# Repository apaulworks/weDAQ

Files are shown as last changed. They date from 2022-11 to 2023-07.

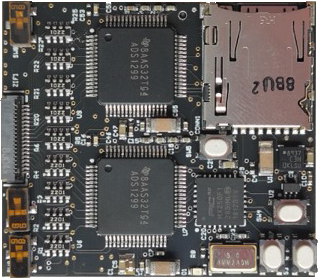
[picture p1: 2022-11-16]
images/Top board view.png

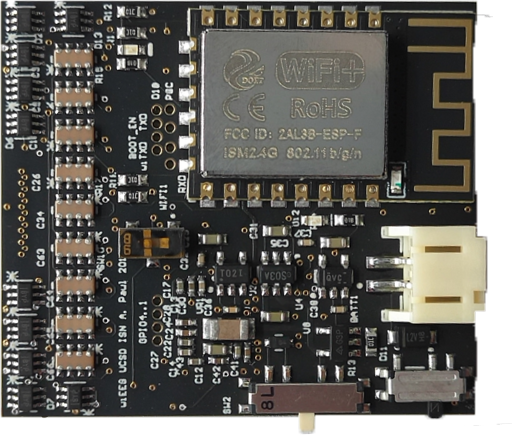
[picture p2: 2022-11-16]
images/Bottom board view.png

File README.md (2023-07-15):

# Wireless Electrophysiology Data Acquisition System (weDAQ)
 Hardware design files and PCB fabrication outputs for the Wireless Electrophysiology Data Acquisition (weDAQ) system. For more information, see: <br />
 the IEEE ISCAS 2022 Proceedings paper here: https://ieeexplore.ieee.org/document/9937994 <br />
 and the IEEE Transactions on Biomedical Circuits and Systems paper here: https://ieeexplore.ieee.org/abstract/document/10115033

## System Overview
<p align="left">
  banner
</p>
<p align="left">
  Wireless electrophysiology data acquisition (weDAQ) in the setting of a body-sensor network where multiple devices are deployed onto a subject or cohort of subjects.
</p>

## Assembled System 
### Top View
<p align="left">
  banner
  
</p>

### Bottom View
<p align="left">
  banner
</p>

<object data="/images/weDAQ_system_overview.pdf/" type="application/pdf" width="700px" height="700px">
    <embed src="/images/weDAQ_system_overview.pdf/">
        <p>This browser does not support PDFs. Please download the PDF to view it: <a href="/images/weDAQ_system_overview.pdf/">Download PDF</a>.</p>
    </embed>
</object>

Firmware and software repo associated with the weDAQ hardware are made available as well. <br />
Python control script: https://github.com/msl052/WeDAQ_Multi

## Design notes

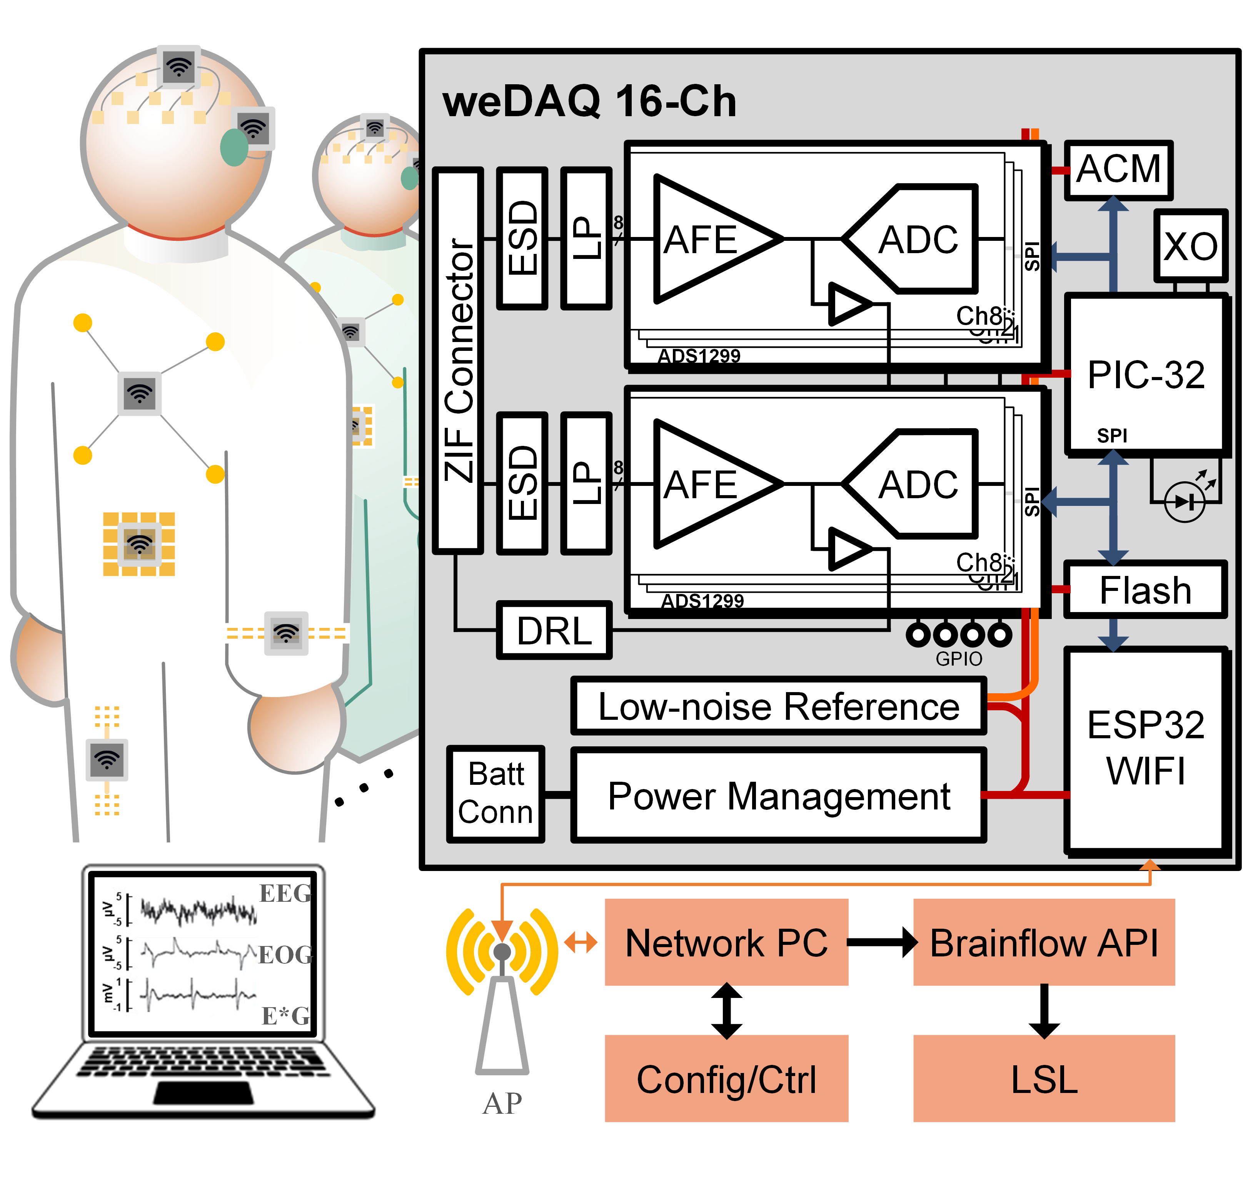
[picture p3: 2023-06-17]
images/Fig1_overview_diagram_2subjects.png

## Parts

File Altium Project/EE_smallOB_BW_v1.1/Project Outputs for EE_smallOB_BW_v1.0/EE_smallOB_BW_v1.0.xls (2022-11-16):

Line # | Name | Description | Designator | Quantity | Manufacturer 1 | Manufacturer Part Number 1 | Manufacturer Lifecycle 1 | Supplier 1 | Supplier Part Number 1 | Supplier Unit Price 1 | Supplier Subtotal 1
1 | S2B-PH-SM4-TB(LF)(SN) |  | BATT1 | 1 | JST | S2B-PH-SM4-TB(LF)(SN) | Unknown | Digi-Key | 455-1749-1-ND | 0.58 | 0.58
2 | GRM188C80G106KE47D | CAP CER 10UF 4V X6S 0603 | C1, C8, C25, C29, C31, C33, C37, C43, C46 | 9 | Murata | GRM188C80G106KE47D | Volume Production | Digi-Key | 490-10469-1-ND | 0.118 | 1.18
3 | GRM31CR60J107ME39K | MURATA - GRM31CR60J107ME39K - COND, 100µF, 6.3V, 20%, X5R, 1206 | C2, C4, C44, C45 | 4 | Murata | GRM31CR60J107ME39K | Obsolete | Digi-Key | 490-7217-1-ND | 0.98 | 3.92
4 | CA064C102K5RACTU | CAP ARRAY 1000PF 50V X7R 0612 | C3, C9, C11, C26, C34, C63, C64, C65, C66 | 9 | KEMET | CA064C102K5RACTU | Volume Production | Digi-Key | 399-9415-1-ND | 0.428 | 4.28
5 | CC0402KRX7R7BB104 | CAP CER 0.1UF 16V X7R 0402 | C5, C10, C12, C13, C15, C24, C28, C41, C47, C51 | 10 | Yageo | CC0402KRX7R7BB104 | Volume Production | Digi-Key | 311-1338-1-ND | 0.031 | 0.31
6 | GRM155R70J105KA12J | CAP CER 1UF 6.3V X7R 0402 | C6, C7, C14, C17, C18, C19, C21, C22, C27, C42, C54, C55, C58, C59, C60 | 15 | Murata | GRM155R70J105KA12J | New Product | Digi-Key | 490-13339-1-ND | 0.079 | 1.19
7 | CC0402KRX7R7BB102 | CAP CER 1000PF 16V X7R 0402 | C16, C53 | 2 | Yageo | CC0402KRX7R7BB102 | Volume Production | Digi-Key | 311-1352-1-ND | 0.019 | 0.19
8 | CC0402JRNPO9BN180 | CAP CER 18PF 50V C0G/NPO 0402 | C20, C23 | 2 | Yageo | CC0402JRNPO9BN180 | Volume Production | Digi-Key | 311-1415-1-ND | 0.1 | 0.2
9 | CC0402KRX7R7BB103 | CAP CER 10000PF 16V X7R 0402 | C30 | 1 | Yageo | CC0402KRX7R7BB103 | Volume Production | Digi-Key | 311-1042-1-ND | 0.1 | 0.1
10 | GRM155C80J225ME95D | 0402 6.3 V 2.2 uF ±20% Tolerance X6S Monolithic Ceramic Chip Capacitor | C32, C35, C36, C38 | 4 | Murata | GRM155C80J225ME95D | Volume Production | Digi-Key | 490-10013-1-ND | 0.12 | 0.48
11 | DM3AT-SF-PEJM5 | CONN MICRO SD CARD PUSH-PUSH R/A | CONN1 | 1 | Hirose | DM3AT-SF-PEJM5 | Volume Production | Digi-Key | HR1964CT-ND | 2.67 | 2.67
12 | LTST-C193TBKT-5A | LED BLUE CLEAR CHIP SMD | D1, D12, D13 | 3 | Vishay Lite-On | LTST-C193TBKT-5A | Volume Production | Digi-Key | 160-1827-1-ND | 0.45 | 1.35
13 | TPD4E1B06DCKR | TVS DIODE 5.5VWM 14.5VC SC70-6 | D2, D3, D4, D5, D6, D7, D15, D16, D17, D18 | 10 | Texas Instruments | TPD4E1B06DCKR | Volume Production | Digi-Key | 296-39346-1-ND | 0.494 | 4.94
14 | CDSU400B | DIODE GEN PURP 80V 100MA 0603 | D8 | 1 | Comchip | CDSU400B | Volume Production | Digi-Key | 641-1003-1-ND | 0.22 | 0.22
15 | MBR120VLSFT3G | MBR120VLSF Series 20 V 1 A Surface Mount Schottky Power Rectifier - SOD-123FL | D11 | 1 | ON Semiconductor | MBR120VLSFT3G | Volume Production | Digi-Key | MBR120VLSFT3GOSCT-ND | 0.4 | 0.4
16 | CAY16-2201F4LF | BOURNS CAY16-2201F4LF RESISTOR, ARRAY-4, 2.2KOHM, 5%, SMD | R1, R2, R3, R4, R6, R20, R21, R22, R23 | 9 | Bourns | CAY16-2201F4LF | Volume Production | Digi-Key | CAY16-2201F4LFCT-ND | 0.121 | 1.21
17 | RC0402JR-071ML | RES SMD 1M OHM 5% 1/16W 0402 | R5, R25 | 2 | Yageo | RC0402JR-071ML | Volume Production | Digi-Key | 311-1.0MJRCT-ND | 0.013 | 0.13
18 | RC0402JR-07470KL | RES SMD 470K OHM 5% 1/16W 0402 | R7, R9 | 2 | Yageo | RC0402JR-07470KL | Volume Production | Digi-Key | 311-470KJRCT-ND | 0.013 | 0.13
19 | RT0402FRE071KL | Res Thin Film 0402 1K Ohm 1% 0.063W(1/16W) ??? }50ppm/??? ? Molded SMD Paper T/R | R8 | 1 | Yageo | RT0402FRE071KL | Volume Production | Digi-Key | YAG1234CT-ND | 0.1 | 0.1
20 | 10K | Res Thick Film 0603 10K Ohm 1% 1/10W ±100ppm/°C Molded SMD Punched Carrier T/R | R12, R13, R16, R17, R18 | 5 | Panasonic | ERJ-3EKF1002V | Volume Production | Digi-Key | P10.0KHCT-ND | 0.1 | 0.5
21 | 1K | Res Thick Film 0603 1K Ohm 1% 1/10W ±100ppm/°C Molded SMD Punched Carrier T/R | R14, R15 | 2 | Panasonic | ERJ3EKF1001V | Volume Production | Digi-Key | P1.00KHCT-ND | 0.1 | 0.2
22 | PTS810SJK250SMTRLFS | SWITCH TACTILE SPST-NO 0.05A 16V | S1, S3, SW4, SW5 | 4 | ITT C&K | PTS810SJK250SMTRLFS | Volume Production | Digi-Key | CKN10503CT-ND | 0.3 | 1.2
23 | CUS-13TB | SWITCH SLIDE SP3T 300MA 4V | SW2 | 1 | Nidec Copal | CUS-13TB | Volume Production | Digi-Key | 563-1103-1-ND | 0.74 | 0.74
24 | SPDT | C & K COMPONENTS - PCM12SMTR - SWITCH, SPDT, 0.3A, 6VDC, SMD | SW6 | 1 | ITT C&K | PCM12SMTR | Volume Production | Digi-Key | 401-2016-1-ND | 0.91 | 0.91
25 | CJS-1200TA | SWITCH SLIDE SPDT 100MA 6V | SW8, SW9, SW10, SW11 | 4 | Nidec Copal | CJS-1200TA | Volume Production | Digi-Key | 563-1021-1-ND | 0.88 | 3.52
26 | LIS3DHTR | ACCEL 2-16G I2C/SPI 16LGA | U1 | 1 | STMicroelectronics | LIS3DHTR | Volume Production | Digi-Key | 497-10613-1-ND | 1.63 | 1.63
27 | SN74LVC1G32DCKR | IC GATE OR 1CH 2-INP SC70-5 | U2 | 1 | Texas Instruments | SN74LVC1G32DCKR | Volume Production | Digi-Key | 296-9848-1-ND | 0.33 | 0.33
28 | LM2664M6/NOPB | IC REG SWTCHD CAP INV 40MA SOT23 | U3 | 1 | TI National Semiconductor | LM2664M6/NOPB | Volume Production | Digi-Key | LM2664M6/NOPBCT-ND | 0.89 | 0.89
29 | TLV70025QDDCRQ1 | LDO Regulator Pos 2.5V 0.2A 5-Pin SOT T/R | U4 | 1 | Texas Instruments | TLV70025QDDCRQ1 | Volume Production | Digi-Key | 296-36764-1-ND | 0.63 | 0.63
30 | ADS1299IPAG | IC AFE 24BIT 16KSPS LN 64TQFP | U6, U9 | 2 | Texas Instruments | ADS1299IPAG | Volume Production | Digi-Key | 296-35009-ND | 55.18 | 110.36
31 | PIC32MX250F128B-I/ML | IC MCU 32BIT 128KB FLASH 28QFN | U7 | 1 | Microchip | PIC32MX250F128B-I/ML | Volume Production | Digi-Key | PIC32MX250F128B-I/ML-ND | 3.68 | 3.68
32 | AP2112K-3.3TRG1 | IC REG LINEAR 3.3V 600MA SOT25 | U8 | 1 | Diodes | AP2112K-3.3TRG1 | Volume Production | Digi-Key | AP2112K-3.3TRG1DICT-ND | 0.47 | 0.47
33 | TPS72325DBVR | 200 mA Low-Noise, High-PSRR Negative Output Low-Dropout Linear Regulators | VR1 | 1 | Texas Instruments | TPS72325DBVR | Volume Production | Digi-Key | 296-39479-1-ND | 2.73 | 2.73
34 | 2491 | ESP8266 SMT MODULE | WIFI1 | 1 | Adafruit Industries | 2491 | Volume Production | Digi-Key | 1528-1438-ND | 6.95 | 6.95
35 | ABMM2-8.000MHZ-E2-T | CRYSTAL 8.0000MHZ 18PF SMD | X1 | 1 | Abracon | ABMM2-8.000MHZ-E2-T | Volume Production | Digi-Key | 535-9628-1-ND | 0.97 | 0.97
36 | FH34SRJ-18S-0.5SH(50) | CONN FFC FPC 18POS 0.50MM R/A | ZIF1 | 1 | Hirose | FH34SRJ-18S-0.5SH(50) | Volume Production | Digi-Key | HFT418CT-ND | 2.17 | 2.17
 |  |  |  | 116

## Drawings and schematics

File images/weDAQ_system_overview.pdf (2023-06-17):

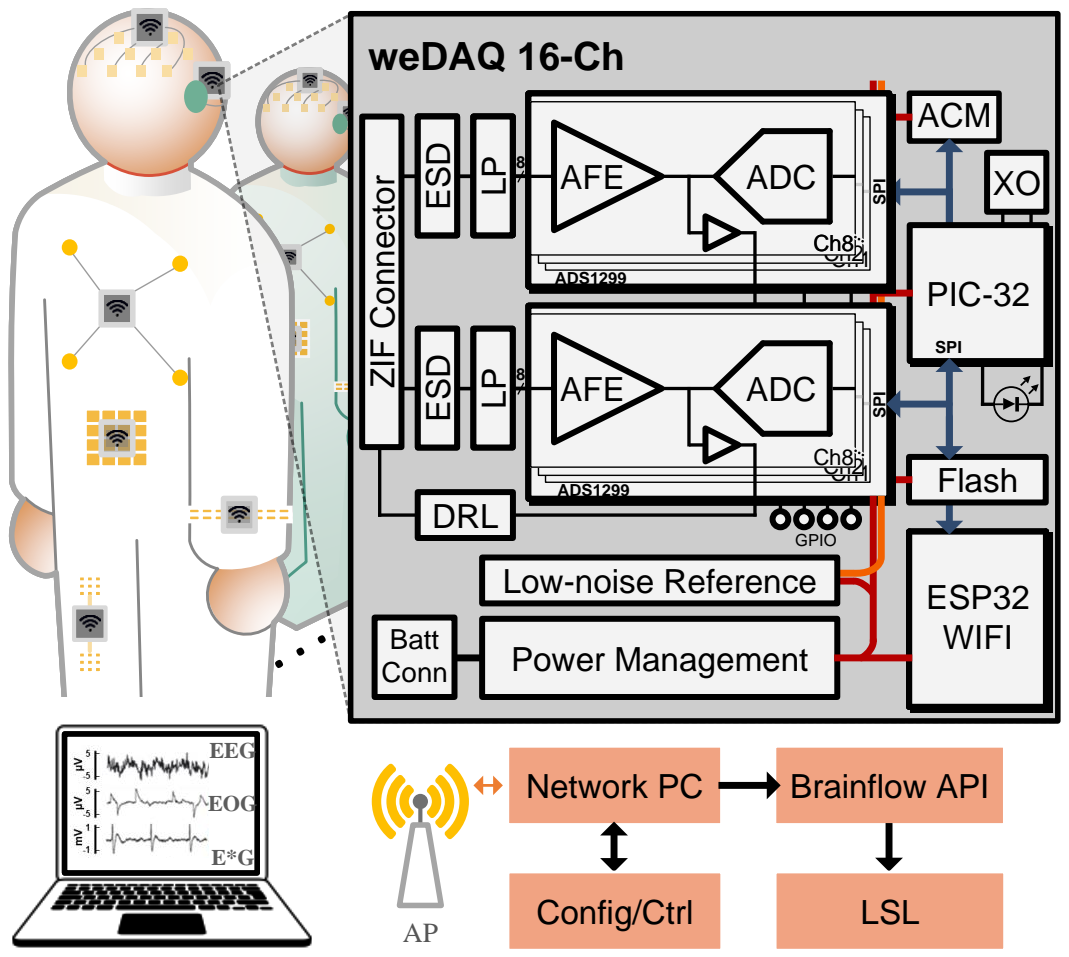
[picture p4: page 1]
ESP32 WIFI; Flash; ACM; PIC-32; DRL; AFE; ADC; ESD; SPI SPI; ADS1299; GPIO; Network PC; Brainflow API; SPI; Config/Ctrl; LSL; EEG; EOG

weDAQ 16-Ch ZIF Connector

Low-noise Reference

Power Management Batt
Conn

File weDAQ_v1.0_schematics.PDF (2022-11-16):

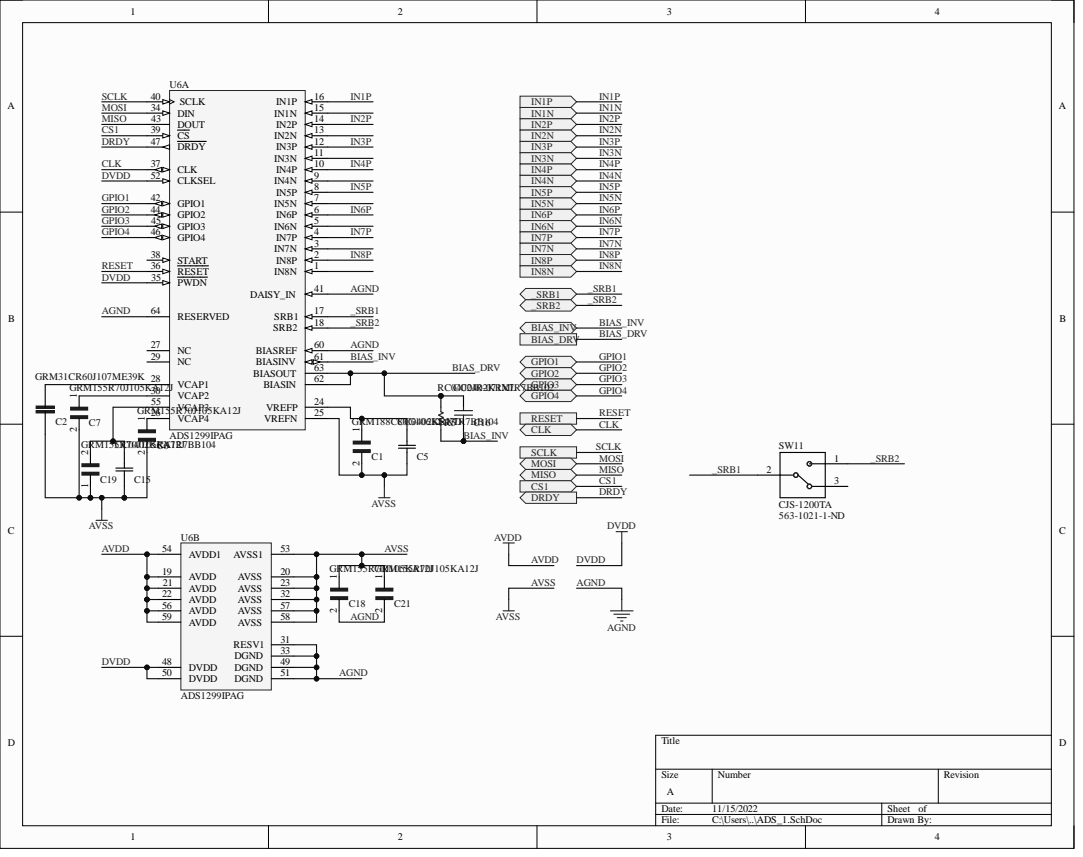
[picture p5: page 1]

GRM1 5R7 CC0 0 4 J 0 1 | 5 2 6 | | 2 5

2 | | | GRM1 | 8 8C8 CC0 0

2 1 | 2 3
2 2 | 3 2
5 6 | | 5 7

3 3
4 9

Size | N u mber | Rev i s i o n

1 1 / 1 5 / 2 0 2 2 | Sheet o f

Fi le: C: \U sers \..\ A DS_ 1.Sch D o c | Draw n By :

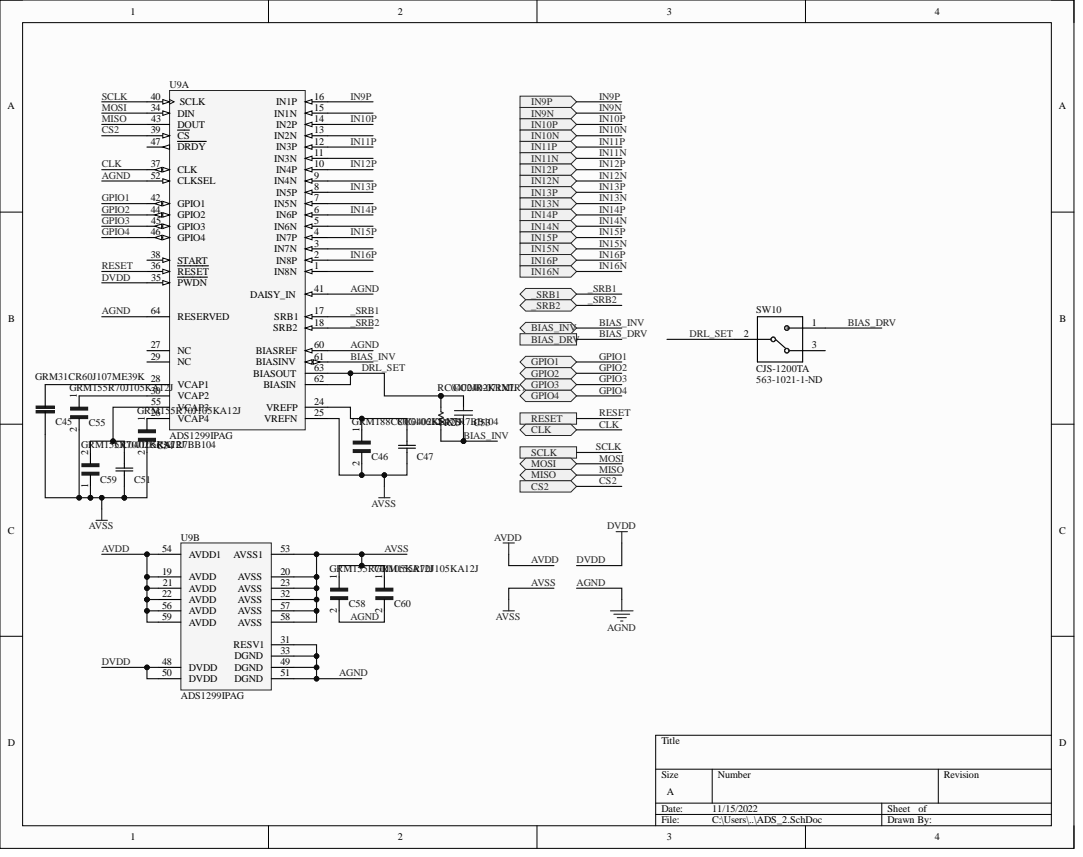
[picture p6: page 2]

6 2 | GPI O

GRM1 5 5R7 0 J 1 0 5 KA 1 2 3 0 | GPI O

GRM1 5R7 CC0 0 4 J 0 1 | 5 2 6 | | 2 5

2 | | | GRM1 | 8 8C8 CC0 0

2 1 | 2 3
2 2 | 3 2
5 6 | | 5 7

3 3
4 9

Size | N u mber | Rev i s i o n

1 1 / 1 5 / 2 0 2 2 | Sheet o f

Fi le: C: \U sers \..\ A DS_ 2.Sch D o c | Draw n By :

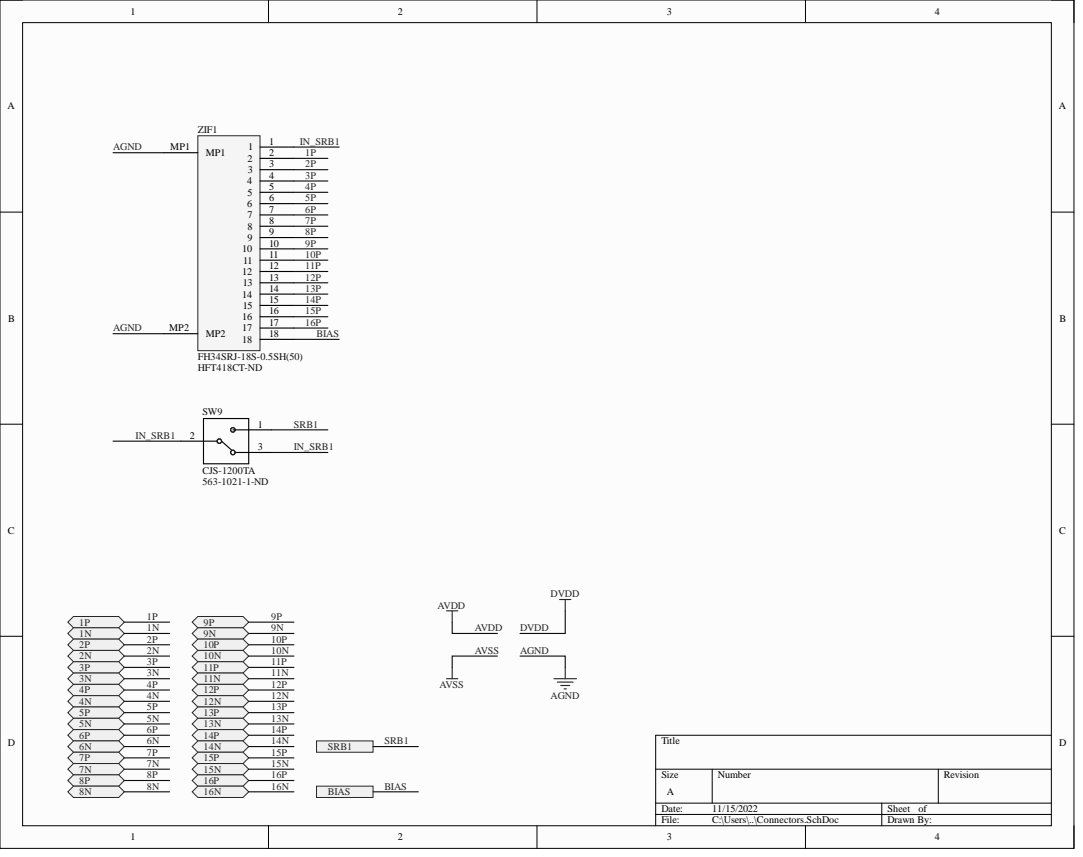
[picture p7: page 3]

Size A | Number | Revision

Date: 11/15/2022 | Sheet of
File: C:\Users\..\Connectors.SchDoc | Drawn By:

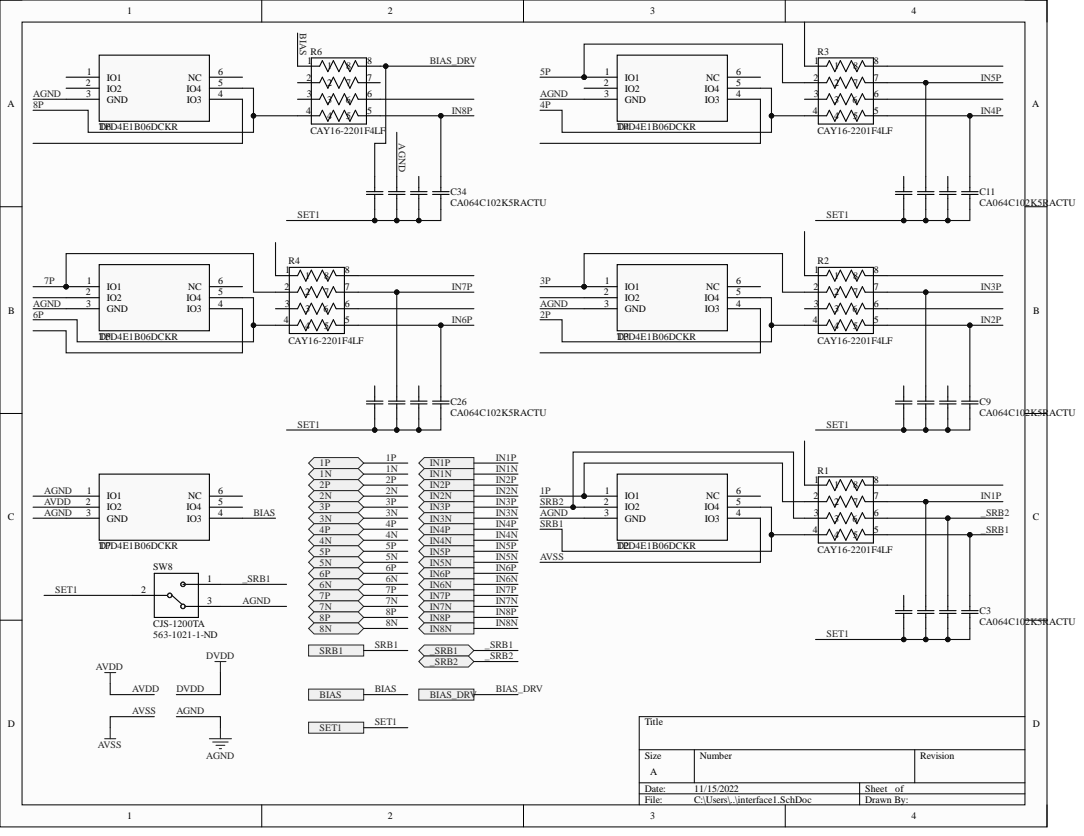
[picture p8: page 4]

Size A | Number | Revision

Date: 11/15/2022 | Sheet of
File: C:\Users\..\interface1.SchDoc | Drawn By:

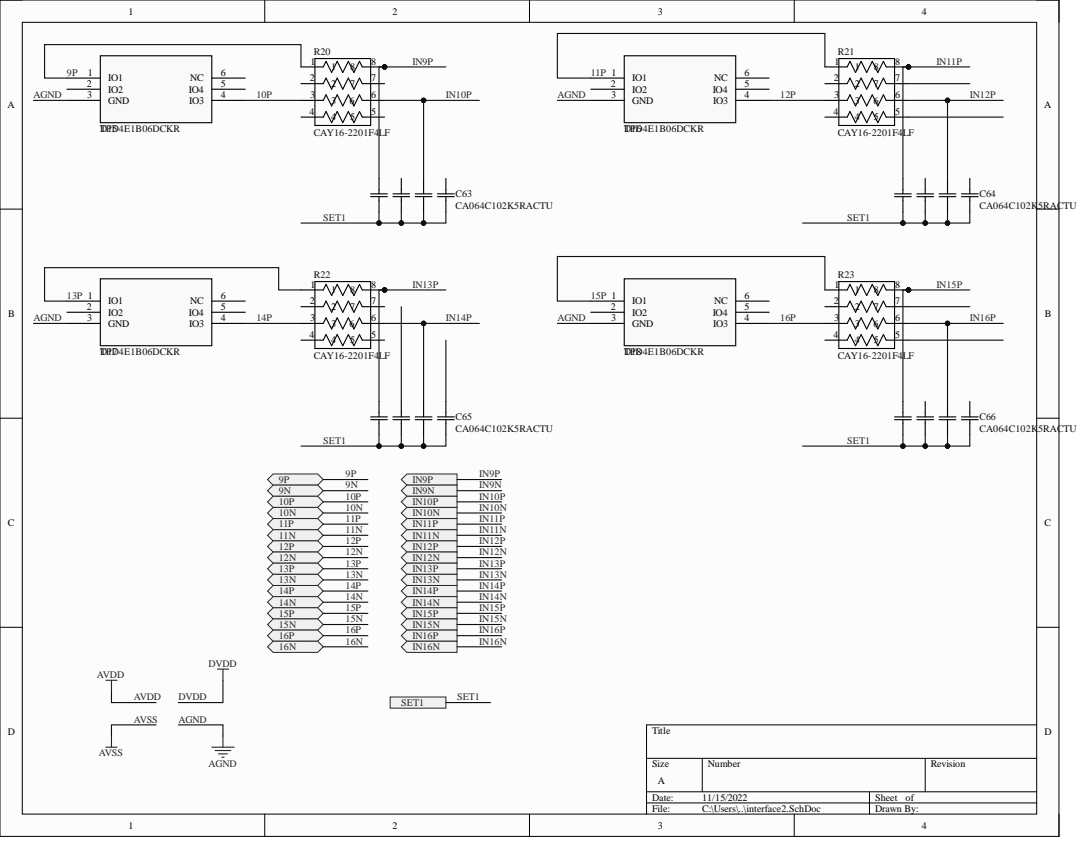
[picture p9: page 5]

Size A | Number | Revision

Date: 11/15/2022 | Sheet of
File: C:\Users\..\interface2.SchDoc | Drawn By:

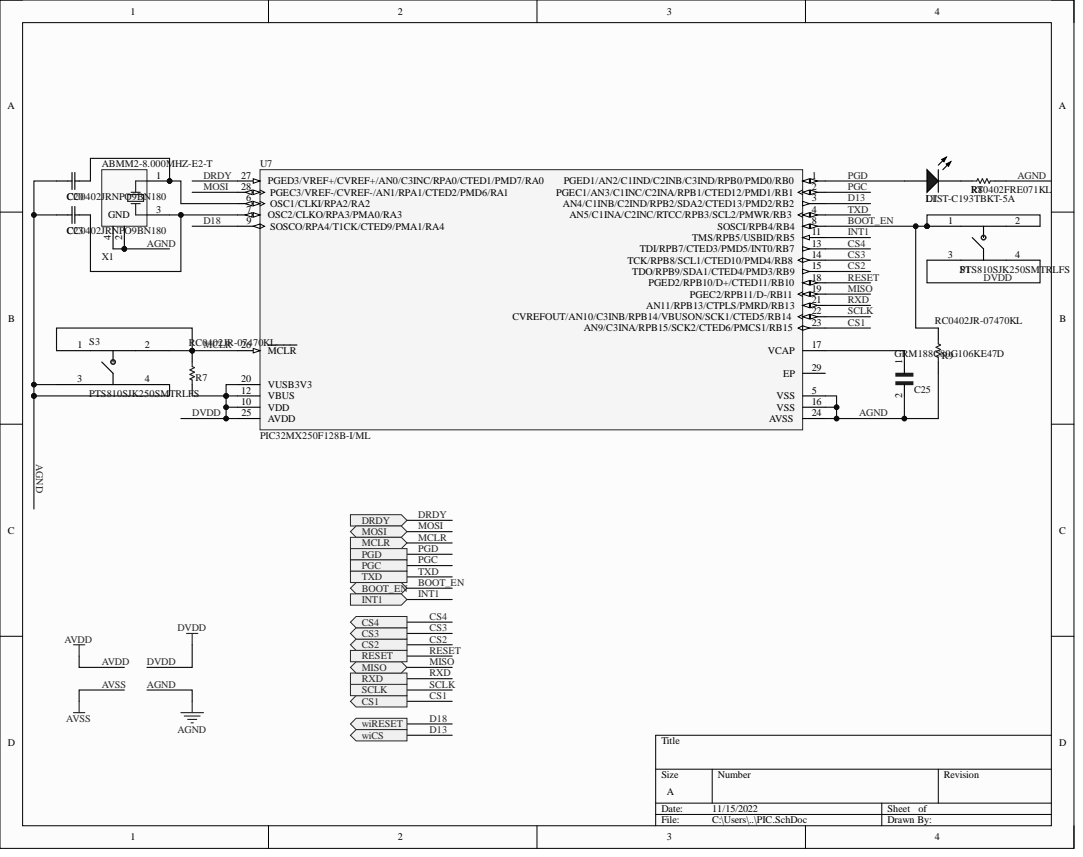
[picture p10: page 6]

Size | N u mber | Rev i s i o n

1 1 / 1 5 / 2 0 2 2 | Sheet o f

Fi le: C: \U sers \..\PIC.Sch D o c | Draw n By :

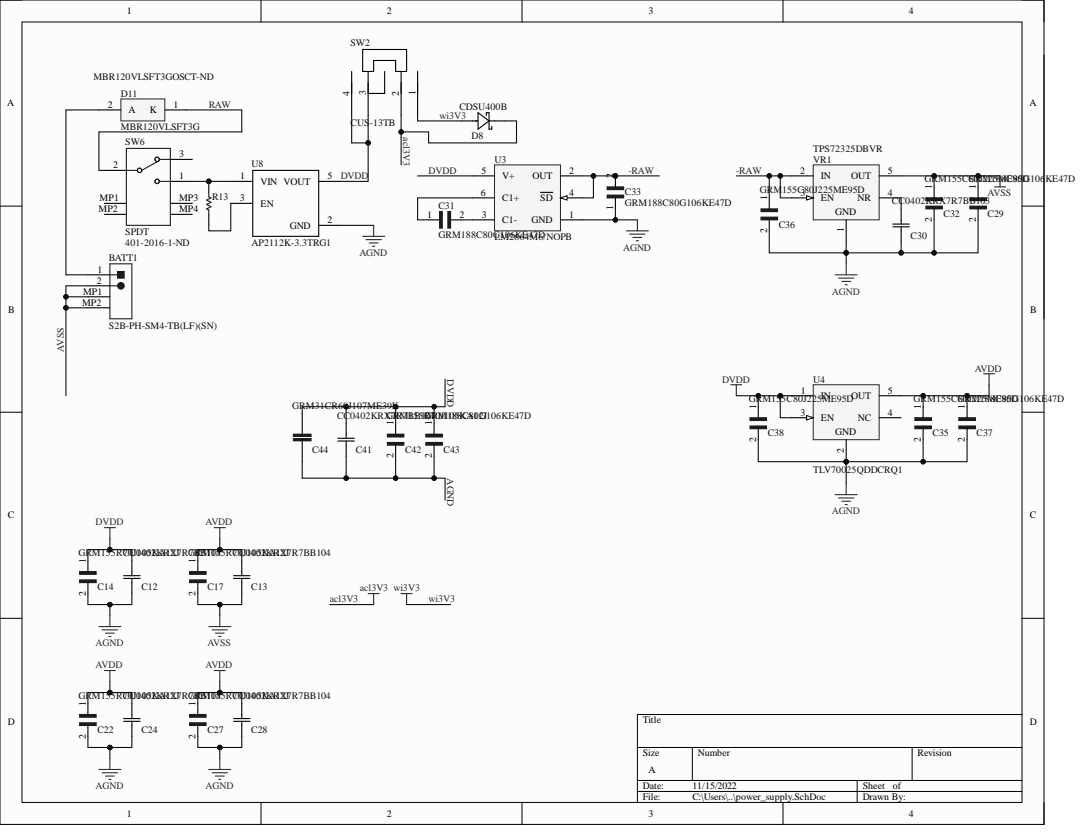
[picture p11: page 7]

GRM155C80J225ME95D

CC0402KRX7R7BB104

Size A | Number | Revision

Date: 11/15/2022 | Sheet of
File: C:\Users\..\power_supply.SchDoc | Drawn By:

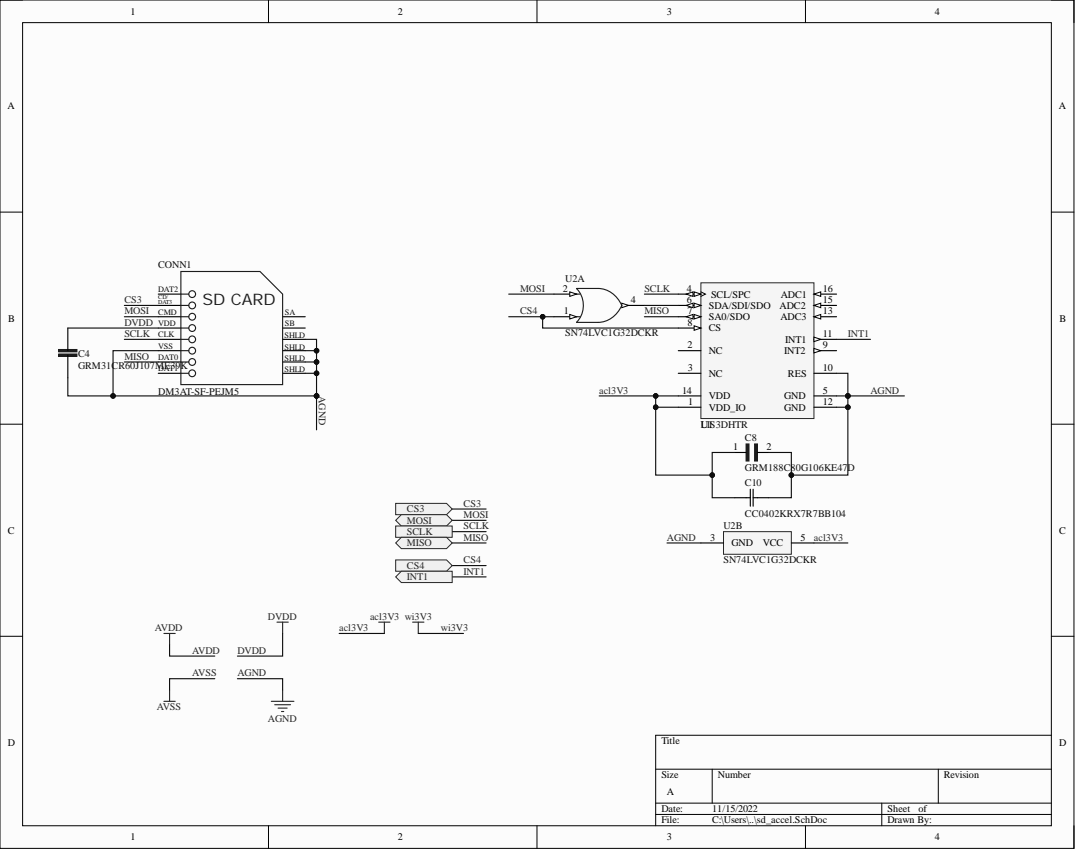
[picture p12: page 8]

Size A | Number | Revision

Date: 11/15/2022 | Sheet of
File: C:\Users\..\sd_accel.SchDoc | Drawn By:

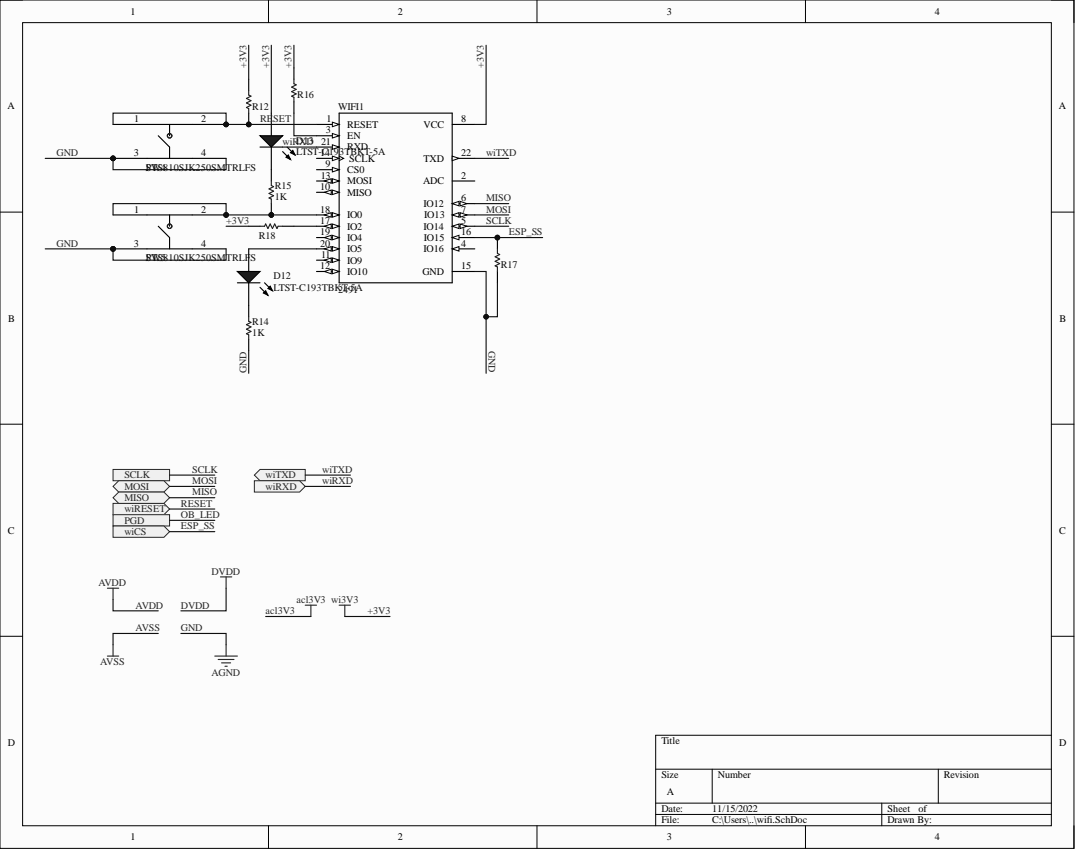
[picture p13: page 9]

Size A | Number | Revision

Date: 11/15/2022 | Sheet of
File: C:\Users\..\wifi.SchDoc | Drawn By:

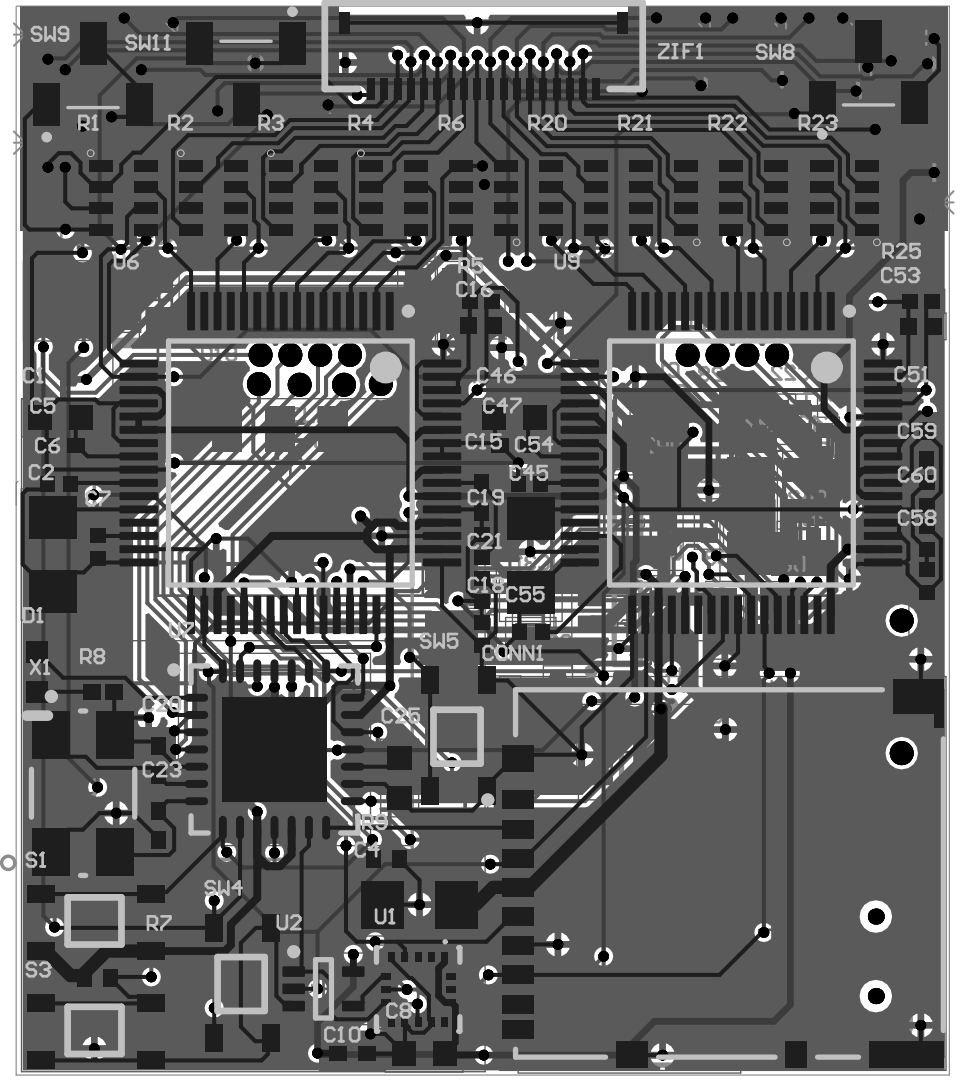
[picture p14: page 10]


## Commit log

2022-11-16 Hardware design and fabrication files for weDAQ v1.1
    [ADS_1.SchDoc, ADS_2.SchDoc, ADS_PIC.SchDoc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]
2022-11-16 Assembled PCB pictures added
